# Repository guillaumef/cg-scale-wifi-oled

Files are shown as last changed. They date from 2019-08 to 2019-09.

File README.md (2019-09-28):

# cg-scale-wifi-oled

A fresh, completely refactored design and rewrote code highly inspired by the original and innovative Olkal cg-scale design.

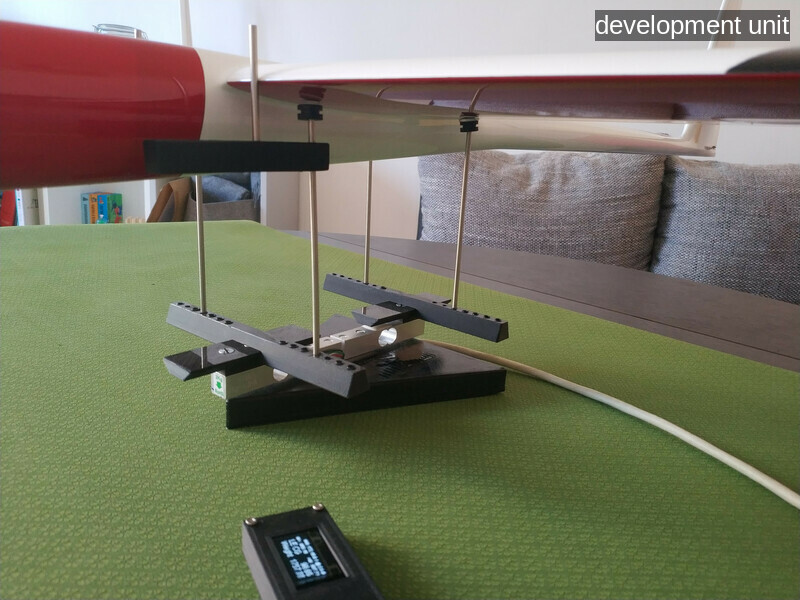
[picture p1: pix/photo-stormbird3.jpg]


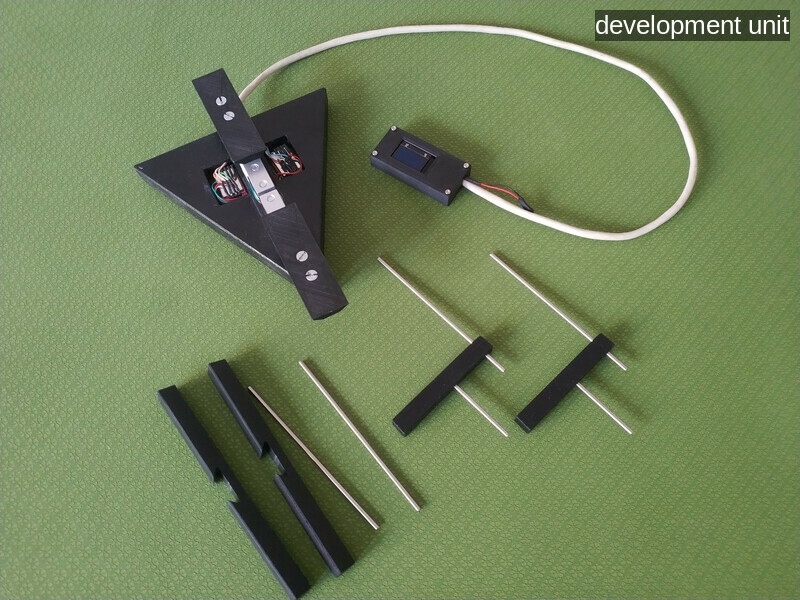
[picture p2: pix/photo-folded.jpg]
CG Scale folded
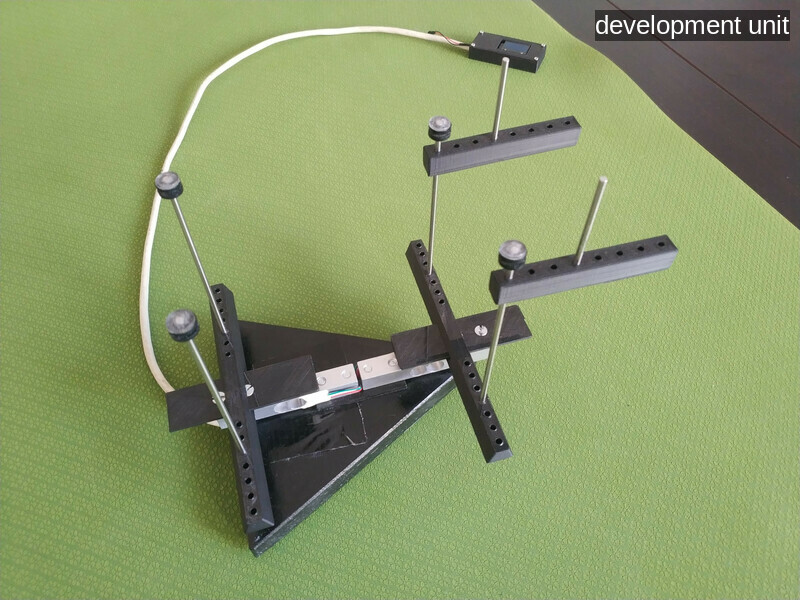
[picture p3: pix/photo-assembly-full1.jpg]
CG Scale ready


## Features

- recent ESP32 wifi-bluetooth-oled board, mainstream and low cost (sub $10) - all-in-one
- minimal and well designed parts (3d printing)
- foldable and easy transport
- manage from a parkflyer, 1m DLG to bigger aerobatic motorised planes (and tunable), and of course F3X gliders
- full remote control: tare, configuration and monitoring via Wifi
- precise tuning
- configuration saved in the ESP32 flash memory
- standalone display with the ESP32 oled
- powered with a simple 1S lipo, a 5V USB battery, Li-Ion 18650, ... 
- multi-language design (included: english, french)
- complete documentation
- easy code upload in the ESP32 with the arduino.cc IDE (few steps documented in 'soft' folder)

The scale 3d parts are parametric and designed with openscad. You can edit the SCAD file and regenerate the STL.

## Comment

Photos were taken from my development unit.
The available parts are now enhanced in strength and stiffness at key points.
Depending on your rc models, you can even trim the rods to lower length to get even more stiffness.
The girder (holding the rods vertically), with its inverted V-shape, is designed to lock itself on the support when a weight is applied.

## Documentation

- [x] Circuit diagram: [CG Scale Circuit Diagram](documentation/circuit-diagram.pdf)
- [x] Assembly: [CG Scale Assembly](documentation/assembly.pdf)
- [x] Manual: [CG Scale Manual](documentation/manual.pdf)
- [x] Soft: [CG Scale Soft](soft/)

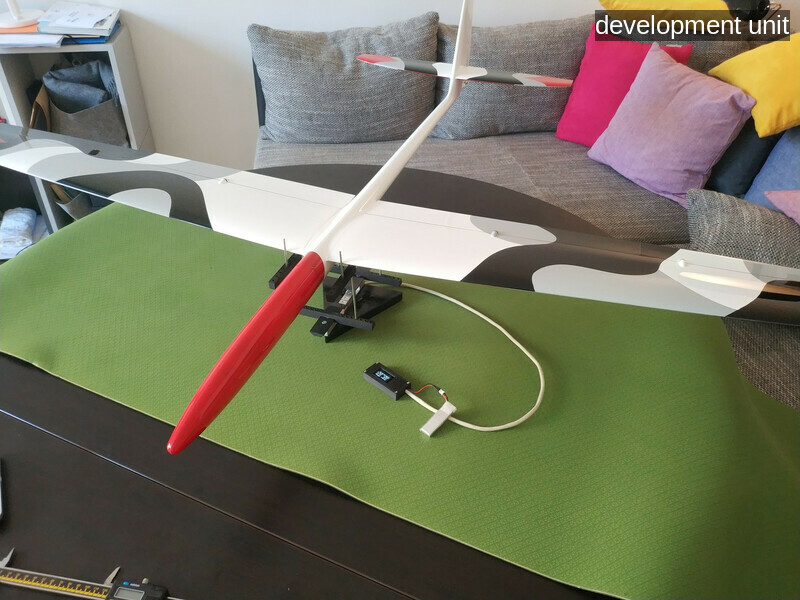
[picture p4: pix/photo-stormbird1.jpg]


## Display/Interface

#### Standalone OLED

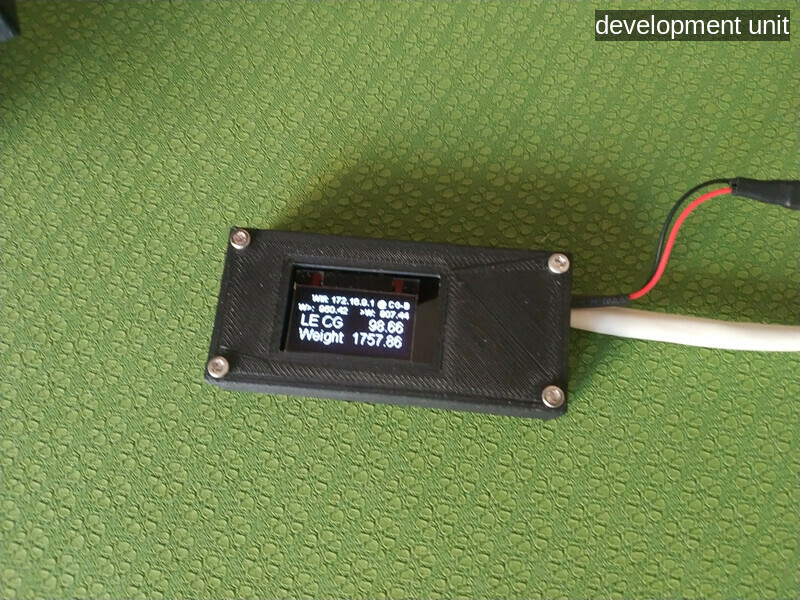
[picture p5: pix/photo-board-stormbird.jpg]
CG Scale board display


#### Wifi interface

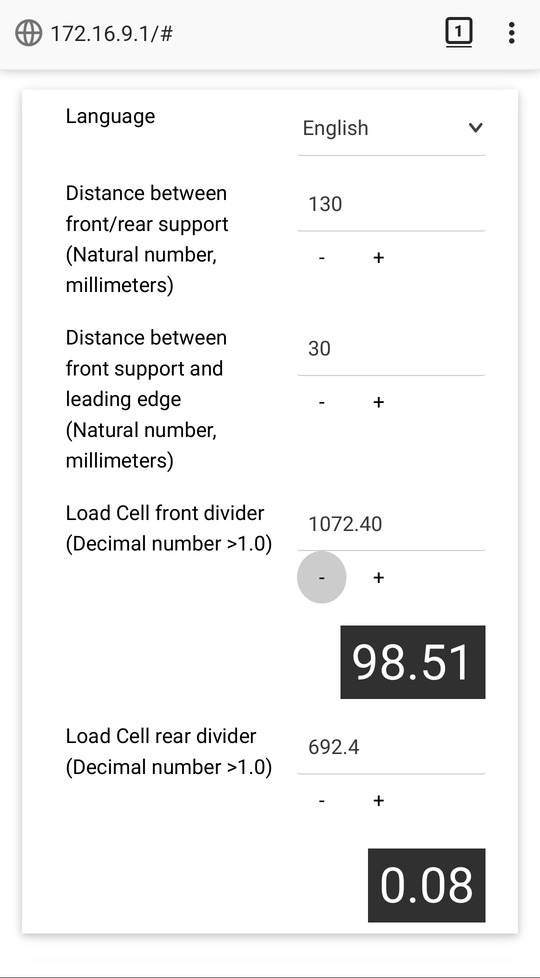
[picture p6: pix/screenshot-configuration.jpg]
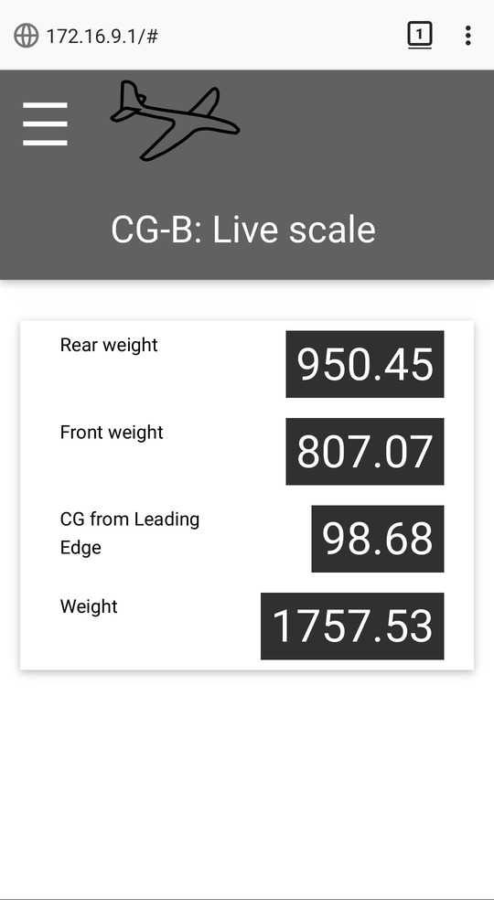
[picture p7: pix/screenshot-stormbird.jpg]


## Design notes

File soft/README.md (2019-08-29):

1) download/install the latest Arduino.cc IDE.

2) in the File > Preferences window in the IDE paste the following line into the Additional Boards Manager URL:

https://dl.espressif.com/dl/package_esp32_index.json

3) go to Tools > Board > Board Manager

4) type ESP32 and Install the new hardware libraries

5) you will be able to find all the ESP32 boards including the Heltec Wifi 32 in the IDE’s board selector:
     "ESP32 Dev Module"

6) go to Tools > Manage Libraries. Search and install those:
     "ESP8266 and ESP32 Oled Driver for SSD1306 display"
     "HX711_ADC"

You are set to compile the 'cgscale.ino' file and flash the board.

Under linux, you can run my Makefile (`make`) to compile and flash to the board.

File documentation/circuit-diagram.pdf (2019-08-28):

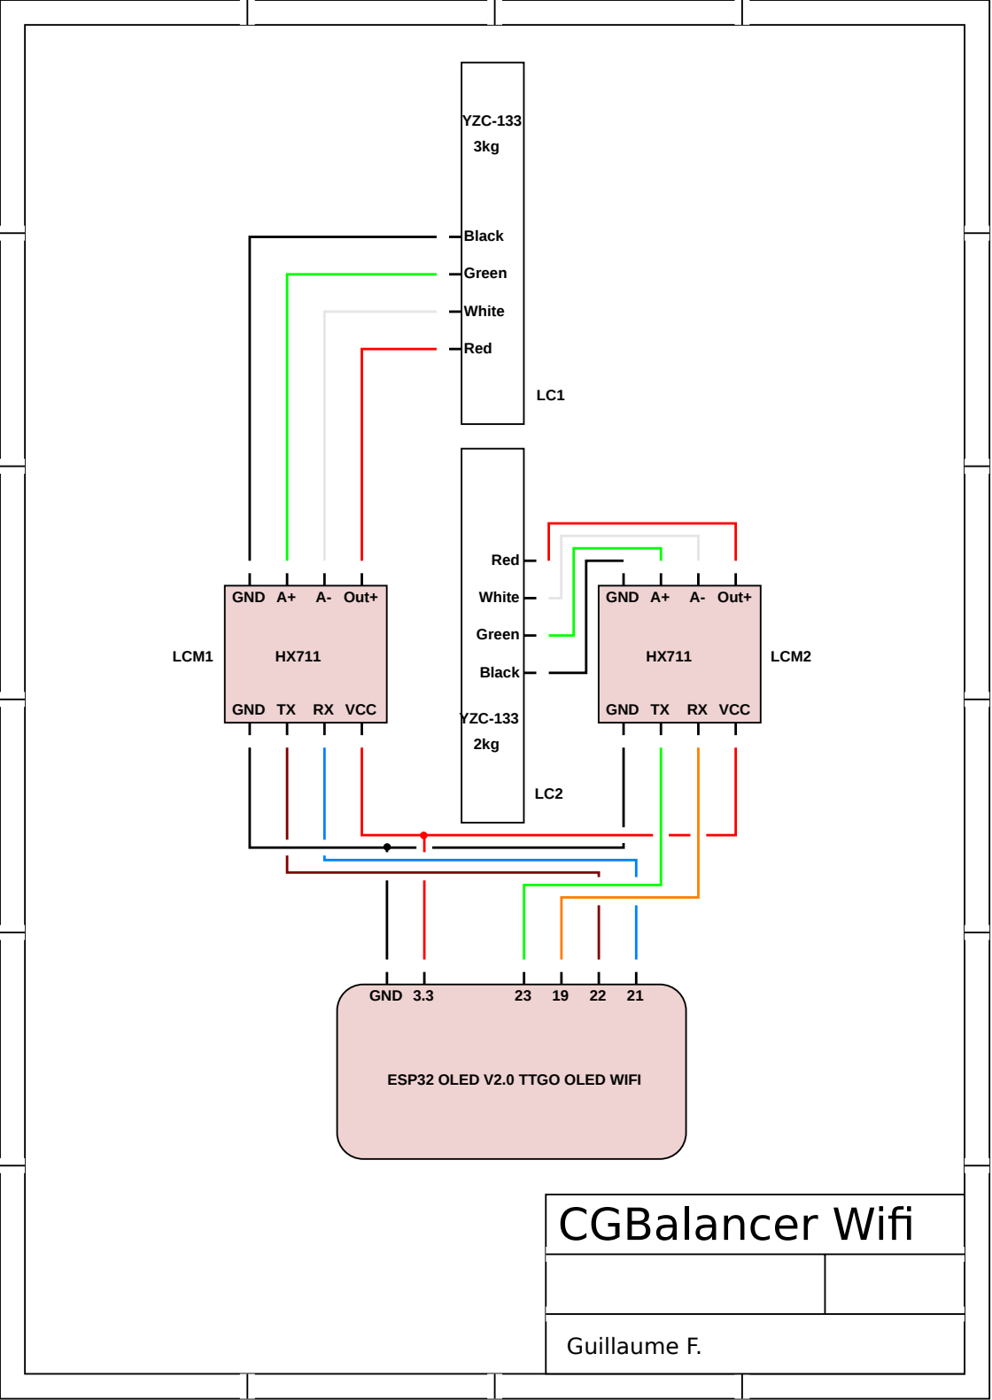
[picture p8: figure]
GND TX RX VCC; GND A+ A- Out+; LCM1; YZC-133; White; Green; Black; Red; LCM2; GND 3.3; ESP32 OLED V2.0 TTGO OLED WIFI; Guillaume F.; CGBalancer Wifi

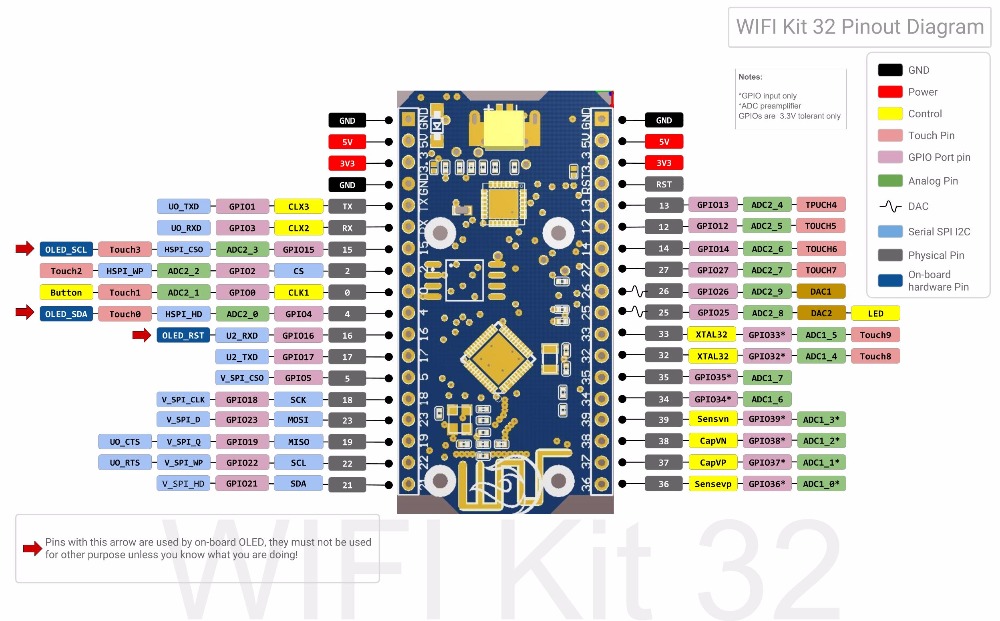
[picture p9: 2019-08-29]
soft/ESP32-TTGO-OLED-DiagramPinout.jpg

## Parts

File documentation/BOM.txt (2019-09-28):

1 x ESP32 OLED V2.0 TTGO (aliexpress)
    "16 Mt bytes (128 Mt bit) Pro ESP32 OLED V2.0 TTGO & for Arduino ESP32 OLED WiFi Modules+Bluetooth Double ESP-32 ESP8266 OLED"
2 x HX711 modules Dual-channel 24-bit A/D (aliexpress - red board - metal shield)
1 x YZC-133 2kg for front scale sensor (aliexpress)
1 x YZC-133 3kg for rear scale sensor (aliexpress)
5 x steel rod 3 mm x ~100-150mm (aliexpress / amazon)
4 x small silicon pad/cap to finish rods end
1 x dead network cable perfect for cabling (scavenging)
4 x screws flat head M4 x 14
4 x screws M5 x 20

Heat Shrink tube
Soldering iron

... and the 3d printed parts.

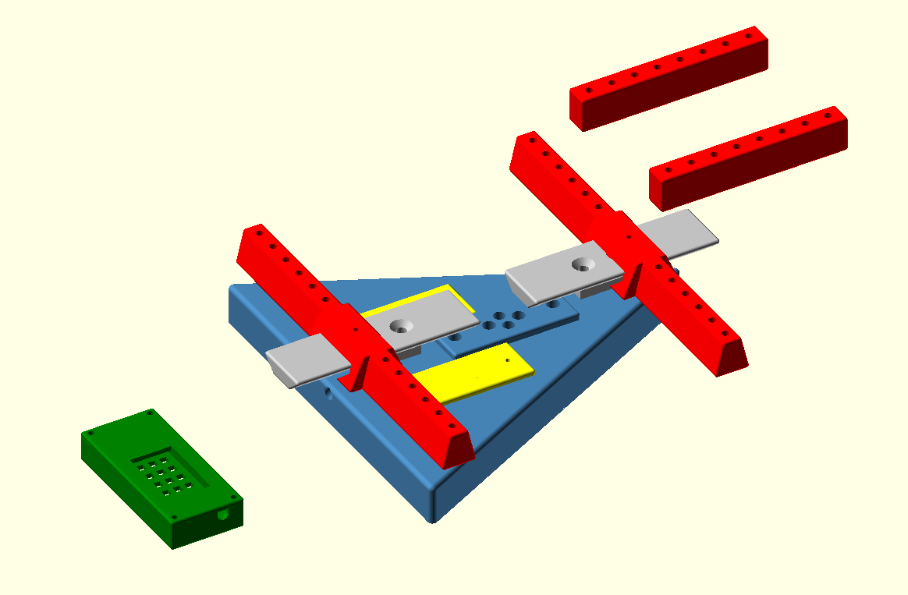
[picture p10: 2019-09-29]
pix/parts-3d-all.png

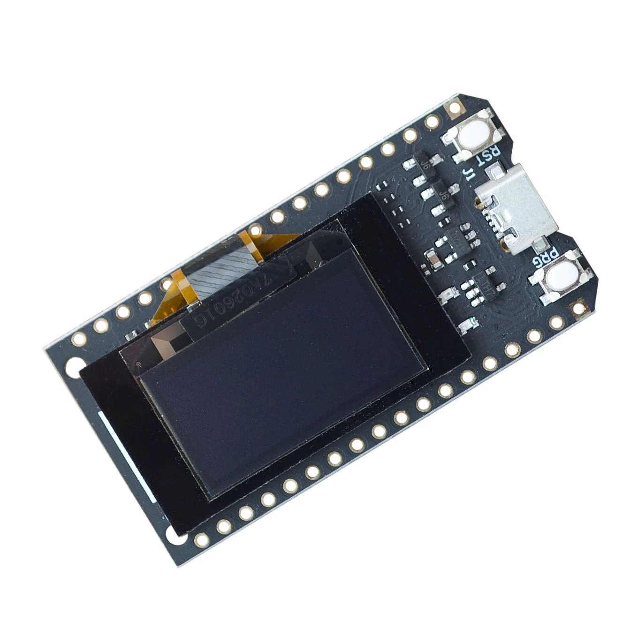
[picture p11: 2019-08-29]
pix/bom-esp32-ttgo-oled-wifi.jpg

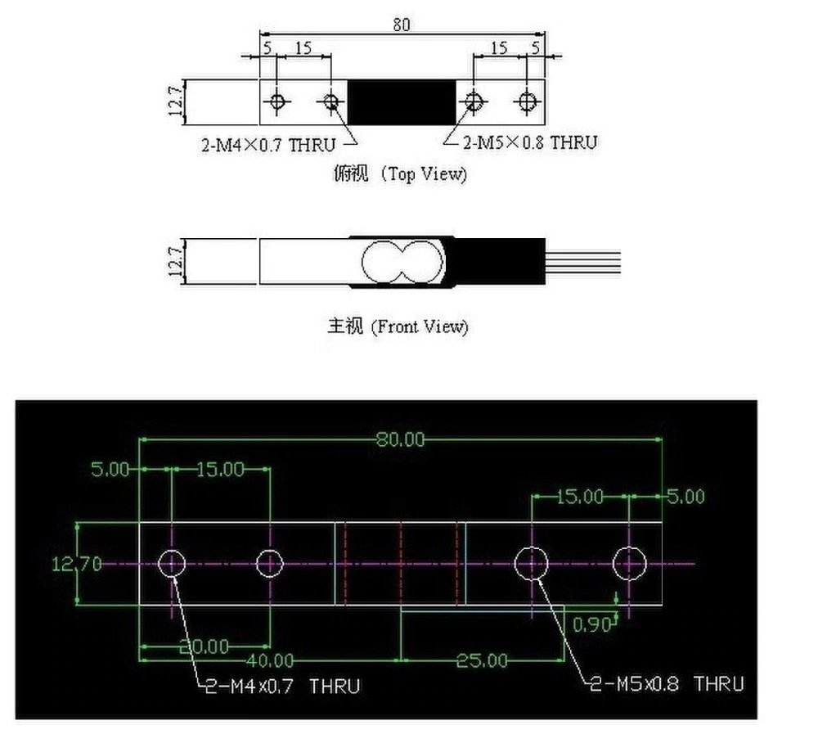
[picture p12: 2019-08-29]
pix/bom-loadcell.jpg

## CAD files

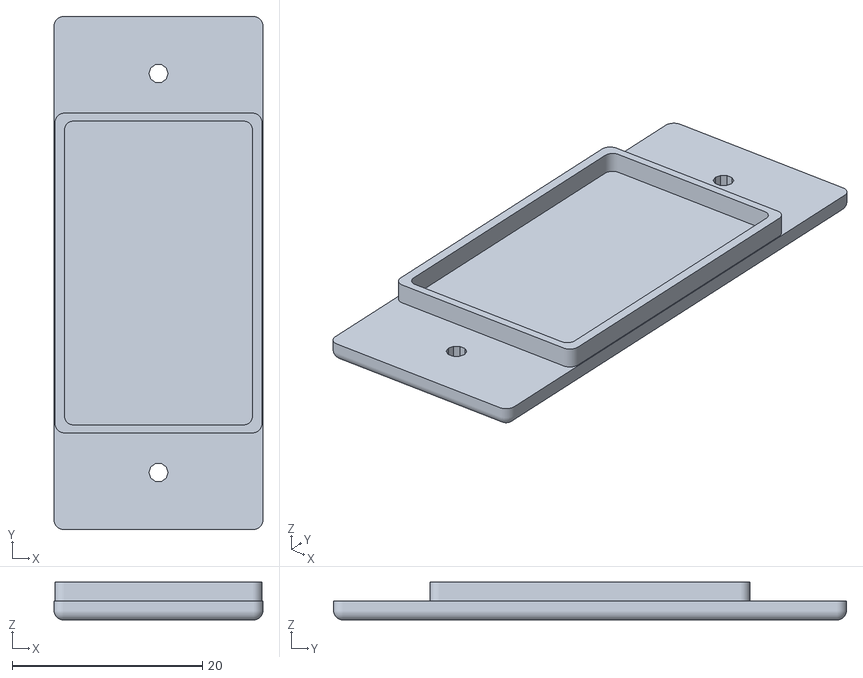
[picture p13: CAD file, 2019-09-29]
parts/stl/base-cover.stl
22.0 x 54.0 x 4.00

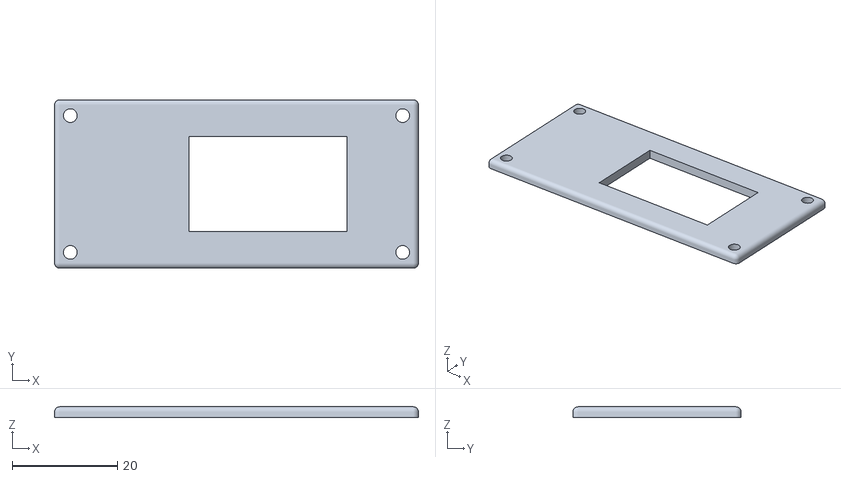
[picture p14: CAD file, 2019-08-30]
parts/stl/case-top.stl
69.2 x 32.0 x 2.00

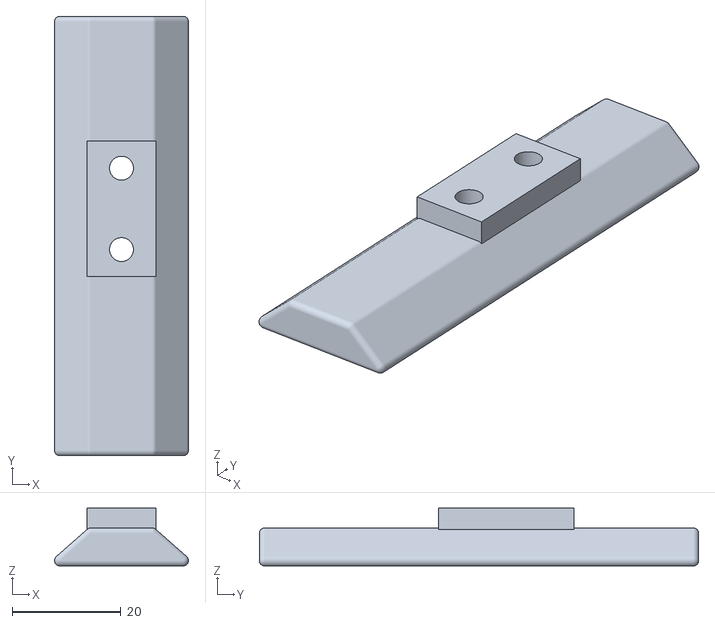
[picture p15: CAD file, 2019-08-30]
parts/stl/support.stl
24.7 x 81.0 x 10.7

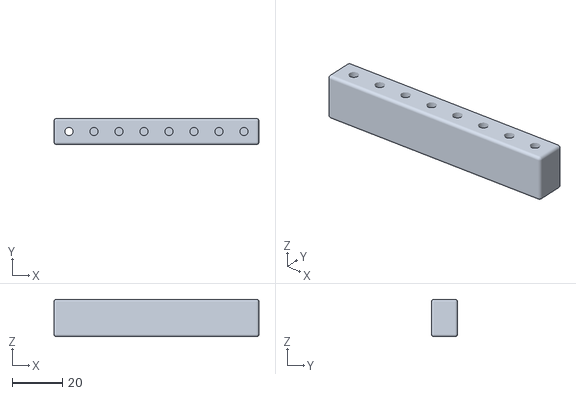
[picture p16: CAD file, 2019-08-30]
parts/stl/le-rod-support.stl
82.0 x 10.5 x 15.0

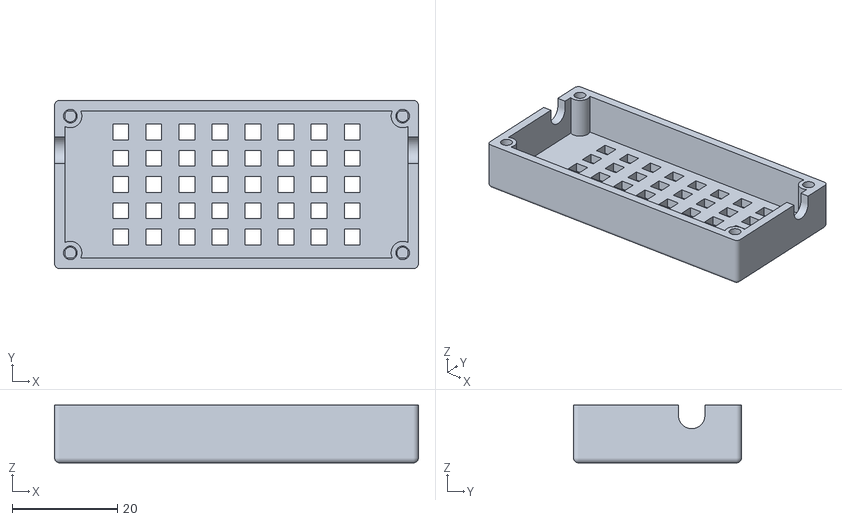
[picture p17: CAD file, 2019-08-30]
parts/stl/case-bottom.stl
69.2 x 32.0 x 11.0

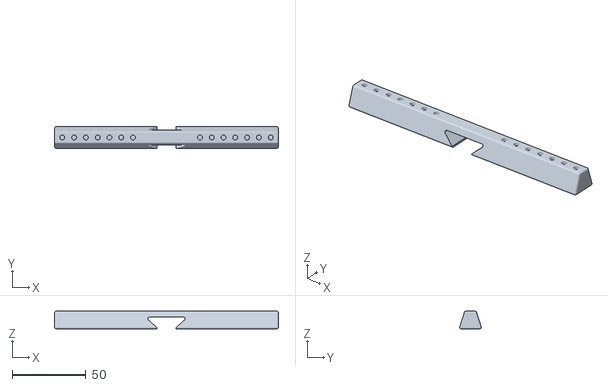
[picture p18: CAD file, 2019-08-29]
parts/stl/rod-support.stl
152.0 x 14.7 x 12.0

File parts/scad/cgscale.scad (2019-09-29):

/*
 * CG Scale
 * Author: Guillaume F. ( g@w0.yt )
 * https://github.com/guillaumef/cg-scale-wifi-oled
 *
 * Work on:
 *    1 - base
 *    2 - support			( x2 )
 *    3 - rod support			( x2 )
 *    4 - leadingEdge rod		( x2 )
 *    5 - case top
 *    6 - case bottom
 *    7 - base scale module cover	( x2 )
 *
 *    9 - display all
 */
WORK_ON = 9;

/* Scale sensor */
ss_wh		= 12.7;	/* x/z */
ss_l		= 80;	/* y */
ss_hole_int_dia	= 5.4;	/* diameter + 0.4 to fit */
ss_hole_ext_dia	= 4.4;	/* diameter + 0.4 to fit */
ss_hole_1 	= 5;
ss_hole_2 	= 20;

/* Scale sensor module */
ssm_w	= 20;
ssm_l	= 32;
ssm_h	= 8;

/* Board */
board_w = 50;
board_l	= 26;
board_h	= 5;
board_oled_w = 30;
board_oled_l = 18;
board_oled_w_pos = 4;
board_clearance = 1;
board_case_thickness = 1; /* with 1 more of the minkowski sphere */
board_case_screw_dia = 2.2;

/* base */
base_w	= 150;	/* width: x */
base_l	= 150;	/* len: depth: y, should be > 2 x ss_l/2 */
base_root_h		= 15;
base_ss_clearance_h	= 4; /* include more with minkowski sphere */
base_ss_clearance_l_space = 3;
base_ss_clearance_l	= (ss_hole_2+ss_hole_1)*2 + base_ss_clearance_l_space;

/* plane support : you can tune */
ps_l_ext	= 39;
ps_l_pos	= 5;
ps_l		= ss_l/2 + ps_l_ext;
ps_lip_h	= 5;

ps_st_l		= 155;
ps_st_h		= 13;
ps_st_hole_depth= 10;
ps_st_hole_dia	= 3.2;	/* 0.2 added to ease the fit - fast drilling in 3mm is mandatory anyway */

$fn=100;


/*
 *
 * SCALE BASE
 *
 */

module base_root() {
	union() {
		difference() {
			minkowski()
			{
				linear_extrude( height = base_root_h )
					polygon( points = [[0, 0],[base_w, 0],[base_w/2,base_l]], convexity = 1 );
				sphere(2);
			}
			/* cut straight the bottom */
			translate([0,0,-base_root_h/2])
					cube([base_w*3,base_l*3,base_root_h], center=true);
		}
		/* ss clearance */
		minkowski()
		{
			translate([base_w/2,base_l/2,base_root_h+base_ss_clearance_h/2])
				cube([ ss_wh+ss_wh/2, base_ss_clearance_l, base_ss_clearance_h ], center=true);
			sphere(1);
		}
	}
}

module base_ss_hole() {
	union() {
		translate([0,0,base_root_h]) {
			cylinder(r=ss_hole_int_dia/2, h=base_root_h*2, center=true);
		}
		cylinder(r=ss_hole_int_dia+2, h=5, center=true);
	}
}
module base_holes() {
	tx = base_w/2;
	ty = base_l/2;
	tz = base_root_h+base_ss_clearance_h/2;
	spacer = base_ss_clearance_l_space/2;
	translate([tx, ty - spacer - ss_hole_1, 0]) base_ss_hole();
	translate([tx, ty - spacer - ss_hole_2, 0]) base_ss_hole();
	translate([tx, ty + spacer + ss_hole_1, 0]) base_ss_hole();
	translate([tx, ty + spacer + ss_hole_2, 0]) base_ss_hole();
}

module base_ssm_hole_mask_hole() {
	translate([0, ssm_l/2 + 5, 0])
		cylinder(r=1,h=1000,center=true,$fn=10);
	translate([0, -(ssm_l/2 + 5), 0])
		cylinder(r=1,h=1000,center=true,$fn=10);
}

module base_ssm_hole_mask_one() {
	minkowski() {
		cube( [ssm_w, ssm_l, ssm_h*2], center=true );
		sphere(1);
	}
}

module ssm_hole_cover() {
	union() {
		difference() {
			translate([0,0,ssm_h+1])
				minkowski() {
					cube( [ ssm_w, ssm_l+20, ssm_h*2], center=true );
					sphere(1);
				}
			translate([0,0,500+2])
				cube([1000,1000,1000],center=true);
			base_ssm_hole_mask_hole();
		}
		difference() {
			translate([0,0,0])
				difference() {
					scale([.99,.99,1])
						translate([0,0,ssm_h+1])
						base_ssm_hole_mask_one();
					scale([.90,.94,1])
						translate([0,0,ssm_h+1])
						base_ssm_hole_mask_one();
				}
			translate([0,0,500+4])
				cube([1000,1000,1000],center=true);
		}
	}
}

module base_ssm_hole_mask() {
	translate([base_w/2 - ssm_w - 2, base_l/2 - ssm_l, base_root_h]) {
		base_ssm_hole_mask_one();
		base_ssm_hole_mask_hole();
	}
	translate([base_w/2 + ssm_w + 2, base_l/2 - ssm_l, base_root_h]) {
		base_ssm_hole_mask_one();
		base_ssm_hole_mask_hole();
	}
}
module base_cablesshole() {
	/* to tune... no complex geometry here - define our vertical hole position */
	ref=37;
	/* ssm hole to under the ss support */
		translate([0,ref/2,2])
		rotate([-90,0,0])
		union() {
			cylinder(r=2.5, h=ref, center=true);
			translate([0,-ref/2+2.5,ref/2])
				rotate([90,0,0])
				cylinder(r=2.5, h=ref, center=true);
		}
}
module base_cablessholes() {
	translate([base_w/2 - ssm_w - 2, base_l/2 - ssm_l, base_root_h-4])
		rotate([0,0,-30])
		base_cablesshole();
	translate([base_w/2 + ssm_w + 2, base_l/2 - ssm_l, base_root_h-4])
		rotate([0,0,30])
		base_cablesshole();
}
module base_cablessmhole() {
	/* to tune... no complex geometry here - define our vertical hole position */
	ref=80;
	/* ssm hole to under the ss support */
		translate([0,0,2.5])
		rotate([-90,0,0])
		union() {
			cylinder(r=2.5, h=ref, center=true);
		}
}
module base_cablessmholes() {
	translate([base_w/2, -2, base_root_h-4])
		rotate([0,0,30])
		base_cablessmhole();
	translate([base_w/2, -2, base_root_h-4])
		rotate([0,0,-30])
		base_cablessmhole();
}
module base() {
	difference() {
		base_root();
		base_holes();
		base_ssm_hole_mask();
		base_cablessholes();
		base_cablessmholes();
	}
}

/*
 *
 * Scale hands
 *
 */
module ps_ss_hole() {
	union() {
		translate([0,0,base_root_h]) {
			cylinder(r=ss_hole_ext_dia/2, h=base_root_h*2, center=true);
		}
		translate([0,0,ss_hole_ext_dia/2])
			cylinder(h=ss_hole_ext_dia+0.1, r1=ss_hole_ext_dia+0.1, r2=0, center=true);
	}
}

module _support_block( w, l, h ) {
	minkowski() {
		translate([-w/2,0,-h/2])
			rotate([90,0,0])
			linear_extrude(height=l,center=true)
			polygon(points = [[0,0],[w/4,h],[w*3/4,h],[w,0]]);
		sphere(1);
	}
}

module _support_block_all() {
	translate([0, -ps_l_pos, ps_lip_h/3]) {
		_support_block( ss_wh+10, ps_l, ps_lip_h );
	}
	translate([ 0, 0, (ss_wh/2 + ps_lip_h)/2 ]) {
		cube([ ss_wh, ss_hole_2+ss_hole_1, ss_wh/2], center=true);
	}
}

module plane_support() {
	difference() {
		translate( [0, (ss_hole_2+ss_hole_1)/2, 0 ] ) {
			_support_block_all();
		}
		translate([0,ss_hole_1,-ps_lip_h/2+0.7])
			ps_ss_hole();
		translate([0,ss_hole_2,-ps_lip_h/2+0.7])
			ps_ss_hole();
	}
}

module rod_support() {
	hole_dia = ps_st_hole_dia;
	difference() {
		rotate([0,0,90]) {
			_support_block( ss_wh, ps_st_l, ps_st_h );
			_support_block( ss_wh*1.8, ss_wh+20, ps_st_h );
		}
		translate([0,0,-2])
		rotate([0,180,0])
			scale([1.03,1.03,1.03])
			_support_block_all();
		cylinder(r=2.1/2,h=100,center=true,$fn=20);
		cylinder(r=4.5/2,h=4,center=true,$fn=6);
		for(x = [ ss_wh+10 : 10 : ps_st_l/2 ]) {
			translate([x,0,ps_st_h - ps_st_hole_depth])
				cylinder(r=hole_dia/2, h=ps_st_h, center=true);
			translate([-x,0,ps_st_h - ps_st_hole_depth])
				cylinder(r=hole_dia/2, h=ps_st_h, center=true);
		}
	}
}

module le_rod_support() {
	hole_dia = ps_st_hole_dia;
	difference() {
		minkowski() {
			cube([ 80, ss_wh*2/3, ps_st_h ], center=true);
			sphere(1);
		}
		/* full hole : thight */
		translate([-35,0,0])
			cylinder(r=hole_dia/2, h=1000, center=true);
		/* rod LE */
		for(x = [ -25 : 10 : 80 ]) {
			translate([x,0, ps_st_h - ps_st_hole_depth])
				cylinder(r=hole_dia/2, h=ps_st_h, center=true);
		}
	}
}

module _case_hole() {
	h = board_h + board_clearance*4 + board_case_thickness*2 + 2; /* +2 for the minkowski sphere */
	translate([0,0,board_case_thickness - 1])
		translate([0,0,h/2 + board_case_thickness*2])
		cylinder(r=board_case_screw_dia/2 + 0.2, h=h + 1, center=true);
}
module _case_screw() {
	h = board_h + board_clearance*4 + board_case_thickness*2 + 2; /* +2 for the minkowski sphere */
	translate([0,0,board_case_thickness - 1])
		difference() {
			cylinder(r=board_case_screw_dia,
					h=h - board_case_thickness, center=true);
			cylinder(r=board_case_screw_dia/2,
					h=h + 1, center=true);
		}
}
module _case() {
	difference() {
		union() {
			difference() {
				minkowski() {
					cube([ board_w + board_clearance*2 + board_case_screw_dia*6 + board_case_thickness*2,
							board_l + board_clearance*2 + board_case_thickness*2,
							board_h + board_clearance*4 + board_case_thickness*2],
							center=true);
					sphere(1);
				}
				cube([ board_w + board_clearance*2 + board_case_screw_dia*6,
						board_l + board_clearance*2,
						board_h + board_clearance*4 ],
						center=true);
				translate([ (board_w - board_oled_w)/2 - board_oled_w_pos, 0, board_h + board_clearance*4 - board_case_thickness*2 ])
					cube([ board_oled_w, board_oled_l, board_case_thickness*6 ], center=true);
			}
			translate([ -board_w/2 - board_case_screw_dia*3, board_l/2, 0 ]) { _case_screw(); }
			translate([ board_w/2 + board_case_screw_dia*3, board_l/2, 0 ]) { _case_screw(); }
			translate([ board_w/2 + board_case_screw_dia*3, -board_l/2, 0 ]) { _case_screw(); }
			translate([ -board_w/2 - board_case_screw_dia*3, -board_l/2, 0 ]) { _case_screw(); }
		}
		translate([ -board_w/2 - board_case_screw_dia*3, board_l/2, 0 ]) { _case_hole(); }
		translate([ board_w/2 + board_case_screw_dia*3, board_l/2, 0 ]) { _case_hole(); }
		translate([ board_w/2 + board_case_screw_dia*3, -board_l/2, 0 ]) { _case_hole(); }
		translate([ -board_w/2 - board_case_screw_dia*3, -board_l/2, 0 ]) { _case_hole(); }
	}
}
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

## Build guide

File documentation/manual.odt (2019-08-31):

# CG Scale configuration

# https://github.com/guillaumef/cg-scale-wifi-oled

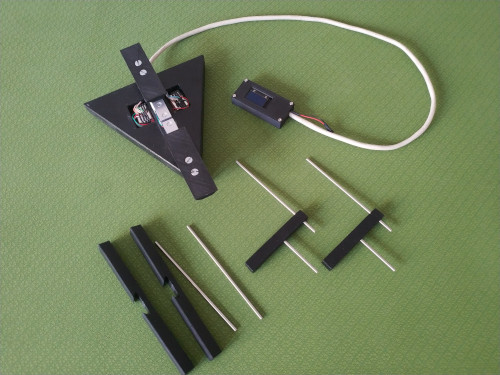
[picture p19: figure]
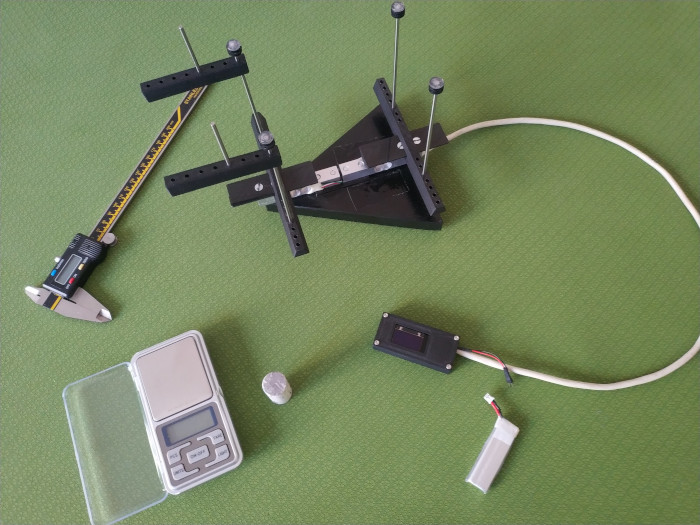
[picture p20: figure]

# First run

Set the scale stable and connect the power of the ESP32.

The first run is displaying:

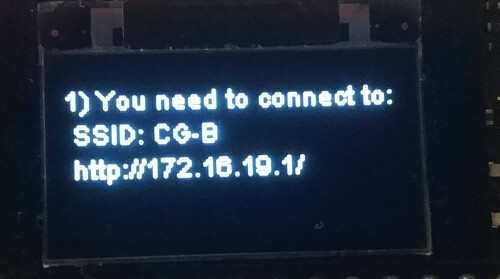
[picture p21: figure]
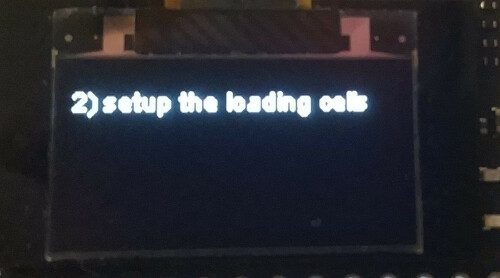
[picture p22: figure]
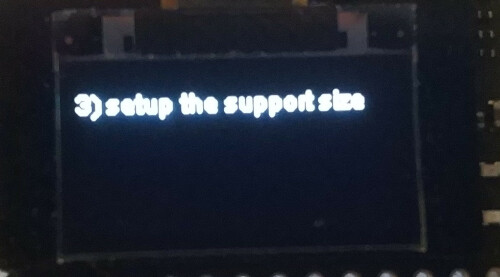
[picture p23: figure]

The ESP32 board opened a Wifi Hotspot named ‘CG-B’.

You can connect your phone/laptop on this SSID (no password).

Your phone/laptop is not going to detect any internet connection, this is normal, stay connected and use your browser to go to the provided address:

http://172.16.19.1/

# Configuration

Left-Top icon holds the menu. Select ‘Configuration’.

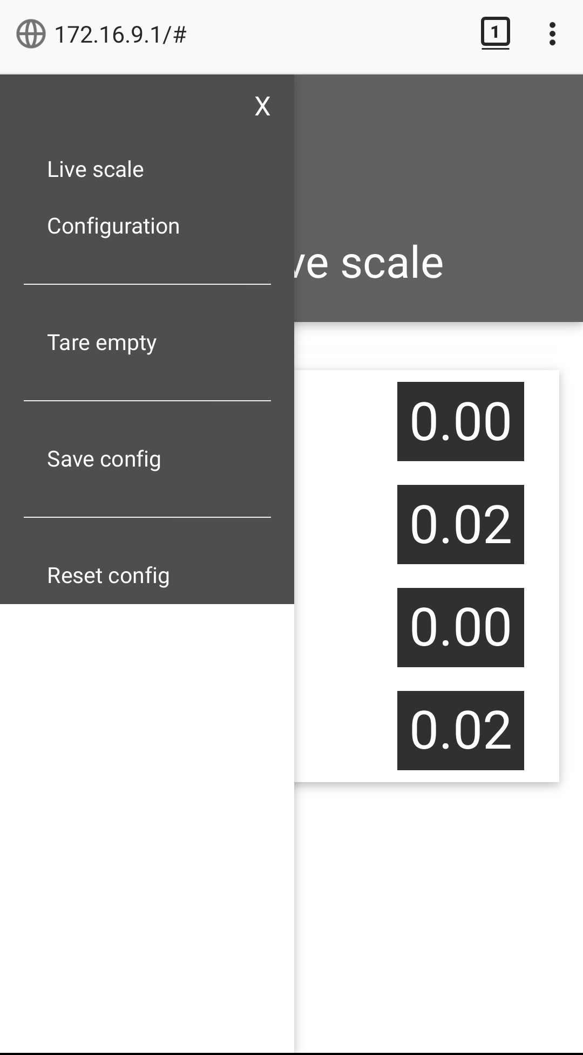
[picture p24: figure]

And this page is displayed:

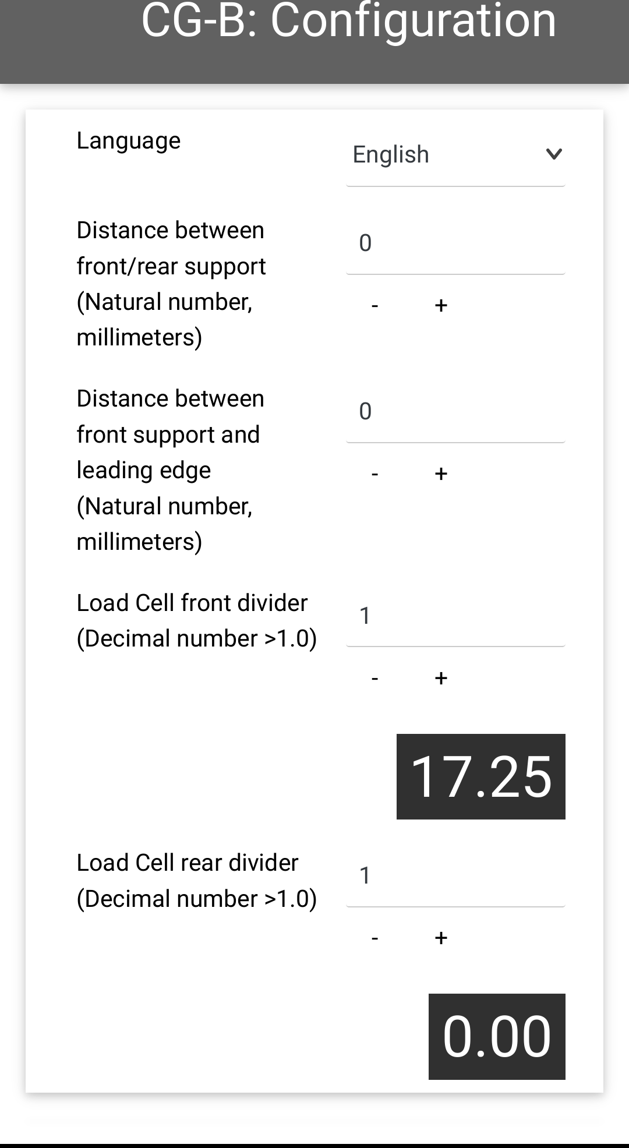
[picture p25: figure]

You have 4 items to configure.

The ~invariable~ ones are the Dividers. We are starting by those.

They are providing to each LoadingCell a common scale to work on. I am using the Gram metric system unit.

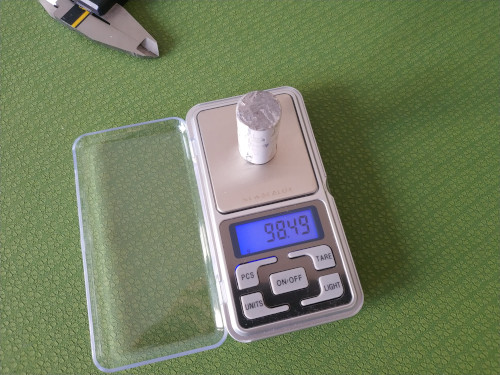
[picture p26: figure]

1. Take a working precision scale and measure a small heavy object (>200gr).

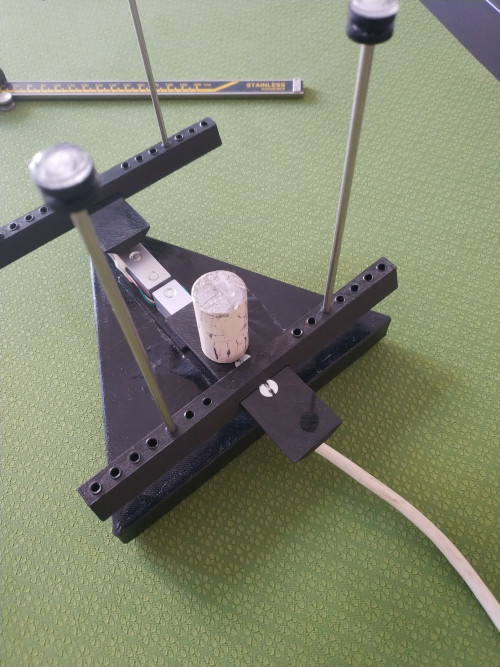
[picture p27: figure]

2. Put this object on a load cell.

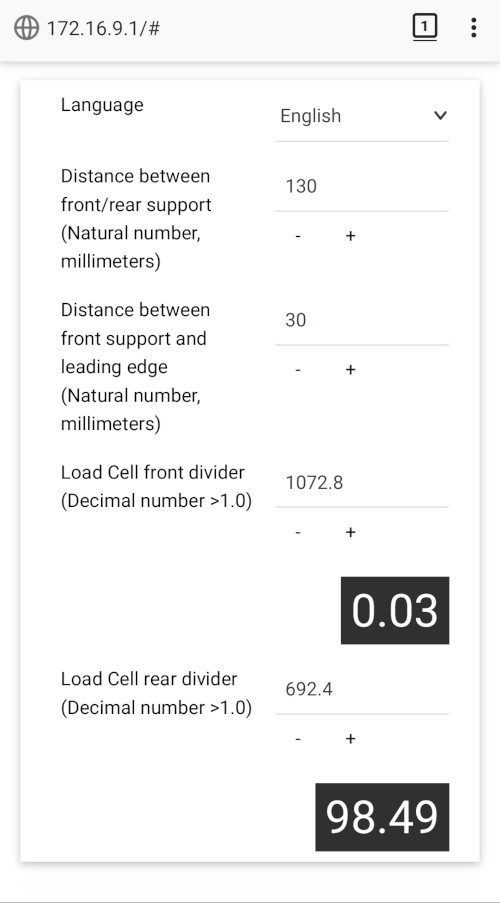
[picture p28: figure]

3. You should see a huge increment in the rear LoadingCell display.
  Change the divider to match the real object weight, typical values are between 500 and 1000.
4. Make the same steps 2-3 for the front LoadingCell

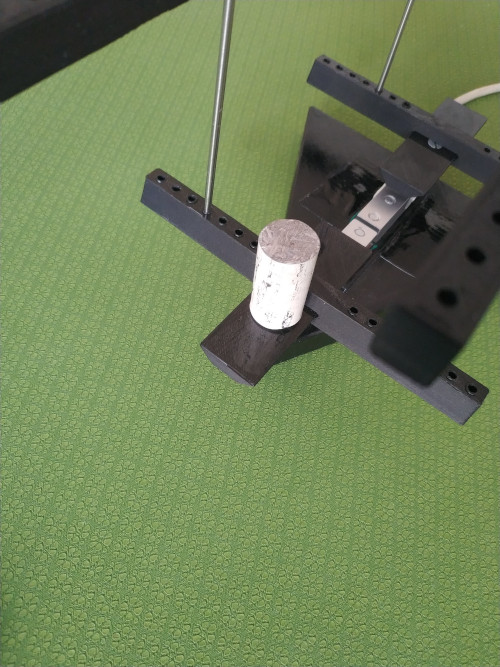
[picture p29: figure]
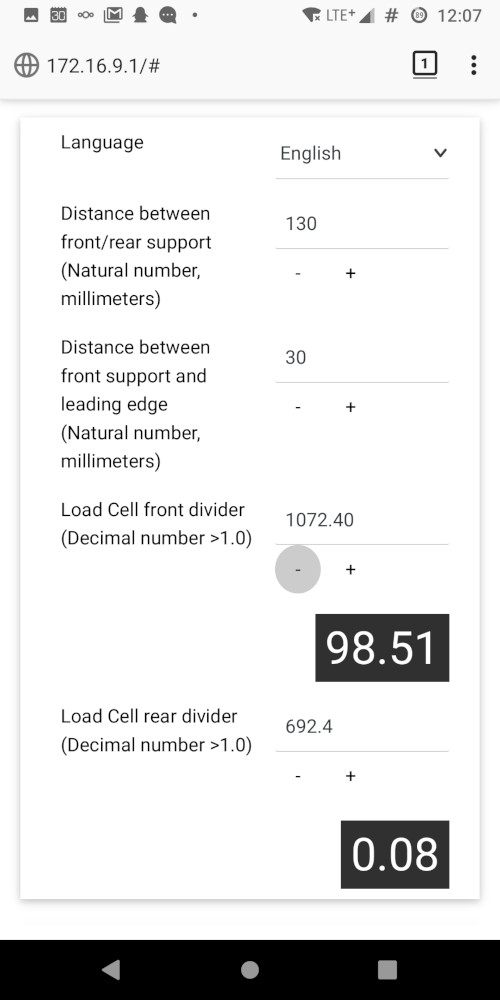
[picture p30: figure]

5. You can save the configuration now (Left-Top menu)
6. This step concerns the more frequent configuration items:

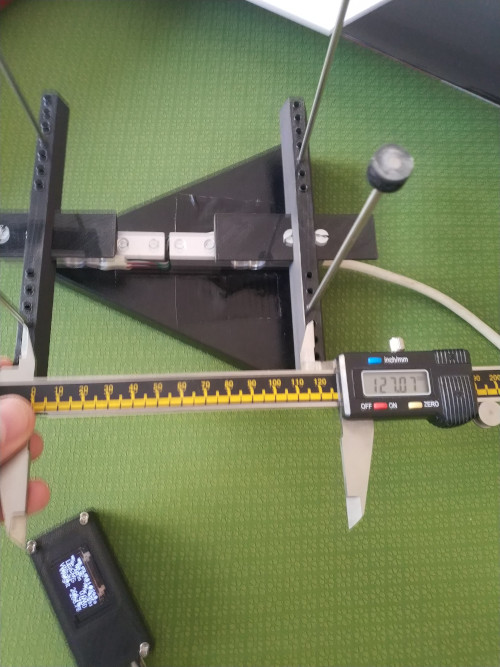
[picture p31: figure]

  1. front rod to rear rod distance:

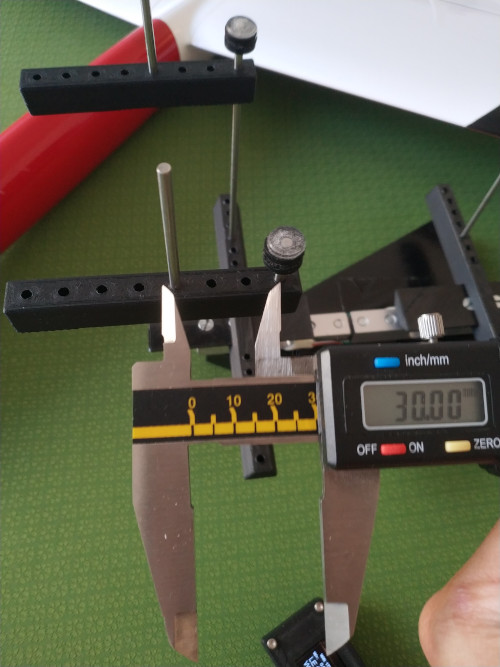
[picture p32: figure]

  1. LeadingEdge rod to front rod distance, this one is easy because each hole is at 10mm from the next one.
  2. Report the values in the configuration and you are ready.

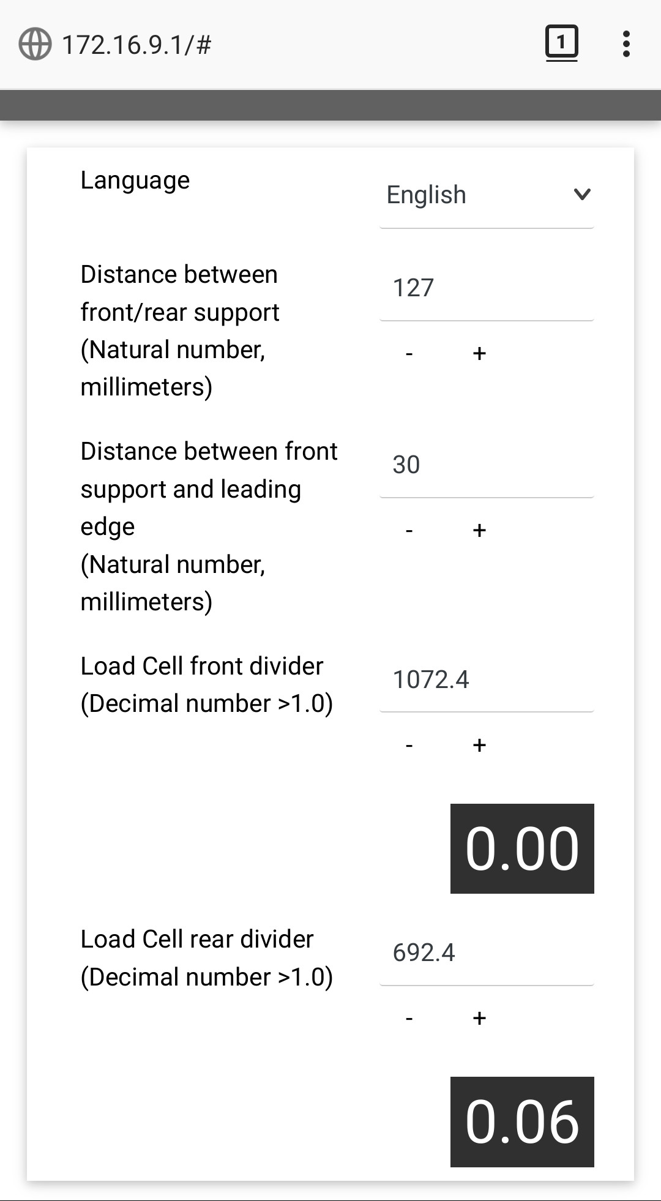
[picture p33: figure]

7. You can save the configuration if you want to keep those two distances or simply set them for the current runtime.

# General: Tare

With the empty scale:

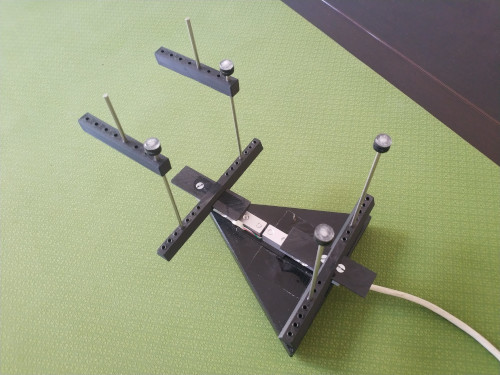
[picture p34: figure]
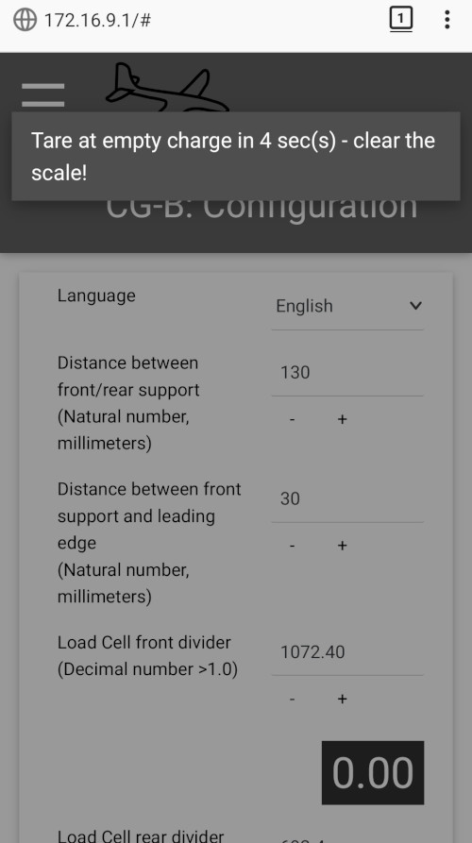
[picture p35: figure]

Click on the Top-Left menu and ‘Tare Empty’.

A countdown is triggered and you have 5 seconds to clear the scale.

The interface tells you when the tare is done (~ 10 seconds for the total procedure).

# Usage

Your CG scale is now fully operationnal, you can put a model on the support rods with the LeadingEdge of the wing against the LE rod.

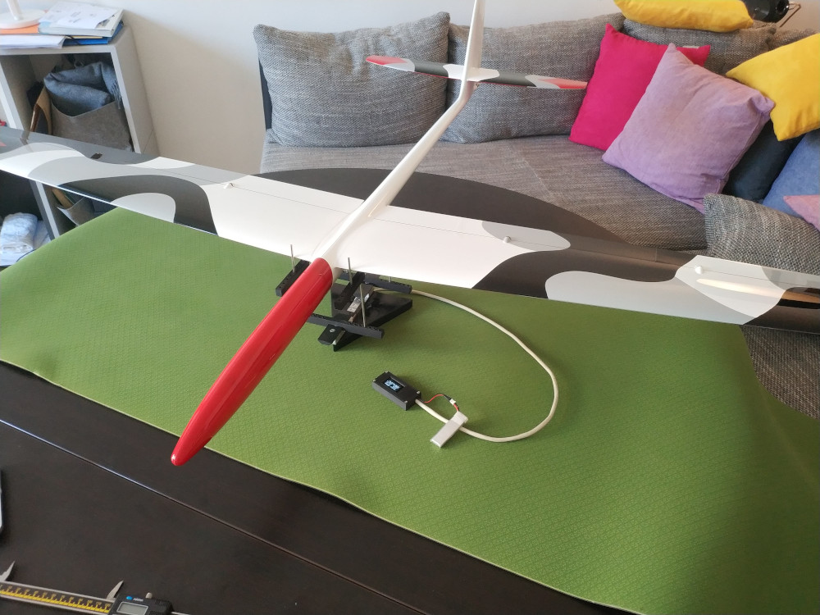
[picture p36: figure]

On the standalone OLED display of the ESP32, you will see a display like this one:

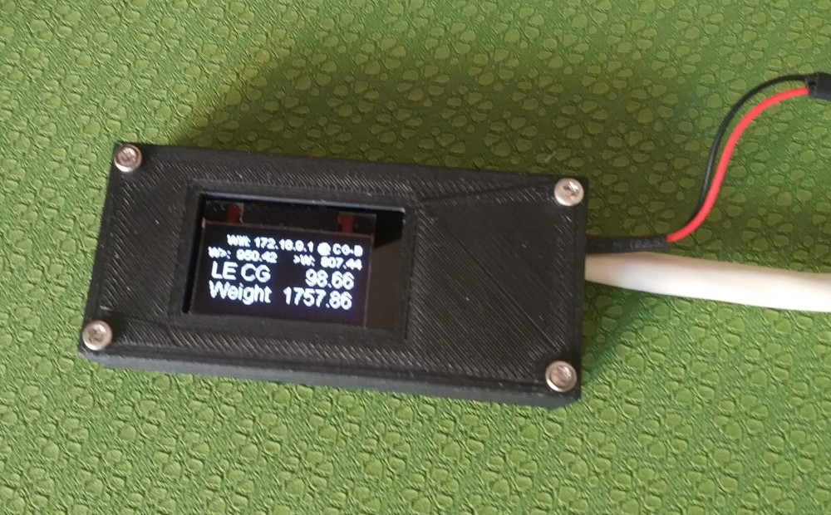
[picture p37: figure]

The ‘live scale’ menu item on your wifi client:

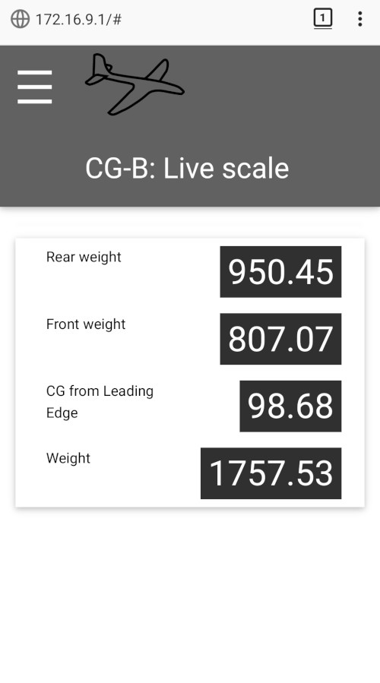
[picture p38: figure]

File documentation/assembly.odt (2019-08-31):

3d parts:

- 1 x base.stl

- 2 x support.stl

- 2 x rod-support.stl

- 2 x le-rod-support.stl

Not mandatory – goodies:

- 1 x case-bottom.stl

- 1 x case-top.stl

1. Take the base.stl part and both LoadingCell
2. Pass the cables of the LoadingCell 3kg throught the hole and screw from the bottom of the base the LoadingCell (floating toward the base large part – the back of the scale)
3. Pass the cables of the LoadingCell 2kg throught the hole and screw from the bottom of the base the LoadingCell (floating toward the base arrow part – the front of the scale)
4. Solder LoadingCell cables to each HX711 module accordingly to the circuit-diagram.pdf (https://github.com/guillaumef/cg-scale-wifi-oled/blob/master/documentation/circuit-diagram.pdf)
5. Prepare a trimmed 8-wires cable (a cat5/6 ethernet cable is a perfect match here) throught the back hole of the base. Partition the 8-wires in two 4-wires and solder them to each HX711 module (circuit-diagram.pdf (https://github.com/guillaumef/cg-scale-wifi-oled/blob/master/documentation/circuit-diagram.pdf))
6. Solder the other end of the 8-wires cable to the ESP32 (circuit-diagram.pdf (https://github.com/guillaumef/cg-scale-wifi-oled/blob/master/documentation/circuit-diagram.pdf))
7. Screw each support.stl parts to each LoadingCell
8. Take a 3mm drill and enhance the quality of all holes on parts: rod-support.stl, le-rod-support.stl
  This step is to perfect the holes to fit the 3mm rods. Don’t over-drill, just follow the printed hole
9. Check a picture of the final cg scale and finalize the build with rods positioning
10. Upload the code in the ESP32 (README.md (https://github.com/guillaumef/cg-scale-wifi-oled/blob/master/soft/README.md))
11. You are now ready and you can read the manual.pdf (https://github.com/guillaumef/cg-scale-wifi-oled/blob/master/documentation/manual.pdf)

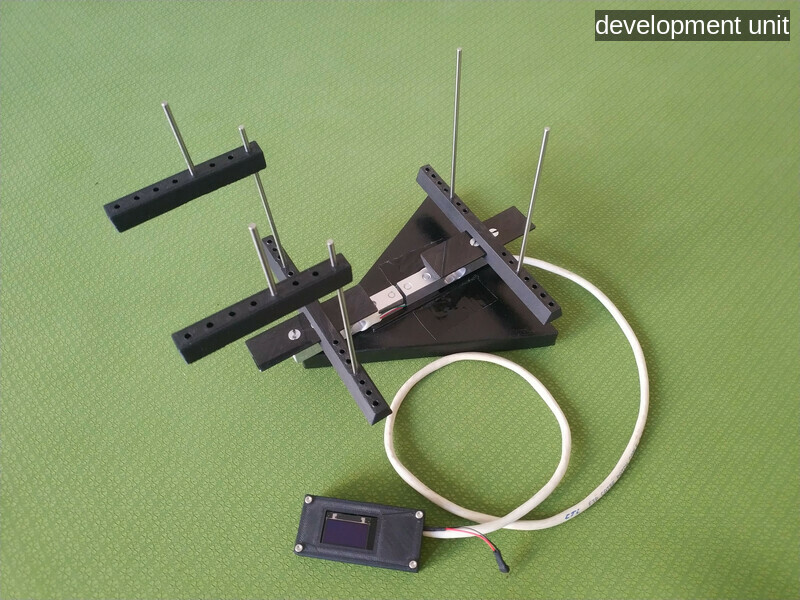
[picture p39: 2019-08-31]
pix/photo-assembly1.jpg

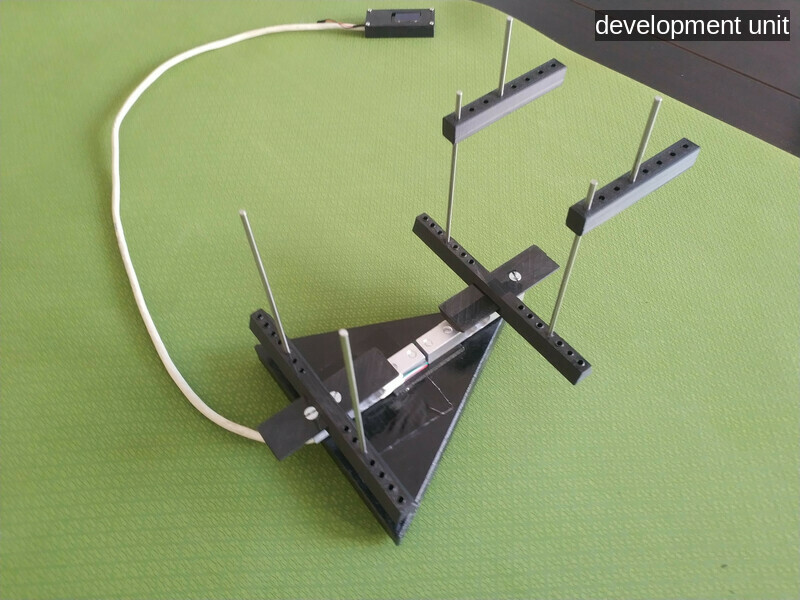
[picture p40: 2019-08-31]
pix/photo-assembly2.jpg

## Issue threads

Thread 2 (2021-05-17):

Reboot after Wifi connection

Prop3r, 2021-05-17:
Bonjour Guillaume,

Thank you for the excellent work and documentation on this CG scale. I'm in the final phase of building the scale, but I'm stuck.

After turning on the device, the splash screen is shown, and after that the instructions to connect to the Wi-Fi appear.
Every time I connect to the Wi-Fi, using my mobile phone, the scale reboots automatically.

I've checked the wiring and boards for continuity and errors, and renewed the scale boards as a precaution, but to no avail.

I've changed the 3,3V connection to the scale boards to 5V. No effect. Main power is provided by a 850mAh 1S lipo (4V).

Do you have any idea what could be wrong?
Is there a log file somewhere I could check?

Cordialement,

Vincent

guillaumef, 2021-05-17:
Bonjour Vincent,

Utilisez-vous la même board que celle que j'ai utilisé?
A mon sens, le problème doit se situer dans le soft et non le hard.
Le Wifi softAP est capricieux, ligne 369-370 - nombreux bugs sont remontés notamment sur les timings.
Essayer d'inserer en ligne 368:
```
    delay(1000);
    WiFi.mode(WIFI_AP);
    delay(1000);
    WiFi.persistent(false);
```

Prop3r, 2021-05-17:
Bonjour Guillaume,

Oui, je Utilisez le ESP32 OLED V2.0 TTGO.

I will try your suggestion, thanks for the quick response!

Cordialement,

Vincent

Prop3r, 2021-05-26:
Bonjour Guillaume,

I was able to successfully connect to the Wifi, without reboots. Thank you!

I could however not connect to the webpage http://172.16.19.1/
After checking the code, I noticed a small error:

IPAddress local_IP(172,16,9,1);
IPAddress gateway(172,16,9,1);

This should be:
IPAddress local_IP(172,16,19,1);
IPAddress gateway(172,16,19,1);

All works now!

Cordialement,

Vincent

guillaumef, 2021-05-28:
Great. I hope you will find it accurate. My two builds are working perfectly (I made a second one with two throw meters and a detachable rj45 cable).

Closed 2021-05-28.

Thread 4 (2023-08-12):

Heltec Wifi kit V2 no longer available, how to make it compatible with V3

Ponpont, 2023-08-12:
Hello,

Many thanks for this project, I had some loadcell available and tried to source a Heltec Wifi Kit V2 but couldn't find any. So I bought a V3 thinking it will be a simple GPIO swap, well long story short, I can't make it work...

Do you think you will be able to port it so it can work on a Heltec Wifi Kit V3 ?

Many thanks,
Pierre

guillaumef, 2023-08-21:
Hi,
It should work with minimal modifications I guess.
Do you successfully compile?

You have to use the provided OLED driver by Heltec it seems and there is a demo here:
https://github.com/HelTecAutomation/Heltec_ESP32/blob/master/examples/OLED/SSD1306UiDemo/SSD1306UiDemo.ino

As far as I can see, there is not much difference in the API, except the includes:
```
#include "heltec.h"
#include "oled/OLEDDisplayUi.h"
```

kabelbrand, 2024-06-29:
Hi,

same here! Found this brilliant scale but the ESP32 is not available. So i got a TTGO  T-Display, tried to implement all libraries, but it doesn't compile. Because i am not a code guy, help will be appreciated....

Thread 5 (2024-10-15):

ESP32

Yanick59, 2024-10-15:
Bonjour,
je souhaite fabriquer votre balance, pouvez vous me conseiller sur l'ESP32 à acquérir ?

Cordialement.

PAT14440, 2024-10-16:
Bonjour,

Si c'est la balance de centrage , c'est celui là

[image: image.png]

Le mar. 15 oct. 2024 à 19:28, Yanick59 ***@***.***> a écrit :

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

Yanick59, 2024-10-16:
Bonjour,

merci de votre réponse mais impossible de voir l'image.......
Si vous avez un lien ça sera plus simple.

Merci

PAT14440, 2024-10-16:
https://fr.aliexpress.com/item/1005006133588398.html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

Le mer. 16 oct. 2024 à 09:35, Yanick59 ***@***.***> a écrit :

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

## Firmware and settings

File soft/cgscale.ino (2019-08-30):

// vim: set ft=c:
/*
 * CG Scale
 * Author: Guillaume F.
 * https://github.com/guillaumef/cg-scale-wifi-oled
 *
 * CG Scale w/ Oled w/ Wifi
 *
 * You can tune the SSID, IP, GPIO, ...
 *
 */

#include <Wire.h>

#include <HX711_ADC.h>

#include <WiFi.h>
#include <WiFiClient.h>
#include <WiFiAP.h>

#include <SSD1306.h>
#include <OLEDDisplayUi.h>

#include <EEPROM.h>


#include "html.h"

/* Uncomment to enable console */
// #define SERIAL_DEBUG

/*
 * Delay loading steps - time to see - set to 0 for fast
 * loading
 */
#define DELAY_STEPS     50

/*
 * Refresh every 1/10th of FPS
 */
#define SCALE_GATHER_FREQ 10

/* LoadCell GPIO */
#define D_LC_FRONT_DOUT	21
#define D_LC_FRONT_SCK	22
#define D_LC_REAR_DOUT	19
#define D_LC_REAR_SCK	  23
#define LC_STABILISING_TIME  4000

/* Wifi SSID */
#define WIFI_SSID       "CG-B"

/* Welcome plane (FPS->seconds) */
#define WELCOME_PLANE   90

/* Do not display negative values */
#define NO_NEGATIVE
/* Max weight tolerate */
#define WEIGHT_MAX      9999.99
/* Min weight on each cell to compute CG */
#define WEIGHT_MIN_CG   30.0

/*
 * Console
 */
#ifdef SERIAL_DEBUG
  void
c_init()
{
  Serial.begin(115200);
  Serial.println();
  Serial.println();
}
  void
c_print( String s )
{
  Serial.println( s );
}
#else
#define c_init()
#define c_print(s)
#endif


/*
 *
 * Conf w/r
 *
 */
#define CONF_MAGIC    ((uint16_t)0xef10)
#define CONF_VERS     ((uint8_t)1)

struct config_s
{
  uint16_t  magic;
  uint8_t   vers;
  uint8_t   lang;
  long		  supports_dist;
  long		  support_le_dist;
  float		  lc_front_calfactor;
  float		  lc_rear_calfactor;
} configuration;

/* EEProm write config at X... if the eeprom is messy */
#define EEPROM_START    0
/* EEProm bytes : EEPROM_START+sizeof(configuration) */
#define EEPROM_SCOPE    (sizeof(configuration) + EEPROM_START)

  int
conf_write( void )
{
  const byte* p = (const byte*)(const void*)&configuration;
  unsigned int i; int addr = 0, modified = 0;
  configuration.magic = CONF_MAGIC;
  configuration.vers  = CONF_VERS;
  for (i = 0; i < sizeof(configuration); i++, addr++, p++) {
    if (*p!=EEPROM.read( EEPROM_START+addr )){
      EEPROM.write( EEPROM_START+addr, *p );
      modified ++;
    }
  }
  EEPROM.commit();
  c_print( "conf_write: wrote "+String(i)+" bytes" );
  return i;
}

  int
conf_reset( void )
{
  memset( &configuration, 0x0, sizeof(configuration) );
  configuration.lc_front_calfactor =
    configuration.lc_rear_calfactor = 1.0;
}

  bool
conf_is_defined( void )
{
  return (configuration.magic == CONF_MAGIC  &&
          configuration.vers == CONF_VERS)
    ? 1 : 0;
}

  bool
conf_is_valid( void )
{
  return (conf_is_defined()                     &&
          configuration.supports_dist>1         &&
          configuration.support_le_dist>1       &&
          configuration.lc_front_calfactor>1.0  &&
          configuration.lc_rear_calfactor>1.0)
    ? 1 : 0;
}

  void
setup_conf( void )
{
  byte* p = (byte*)(void*)&configuration;
  unsigned int i; int addr = 0;

  EEPROM.begin( EEPROM_SCOPE );

  for (i = 0; i < sizeof(configuration); i++, addr++, p++)
    *p = EEPROM.read( EEPROM_START + addr );

  c_print( "conf_readed: " );
  c_print( " version: "+String(configuration.vers) );
  c_print( " supports_dist: "+String(configuration.supports_dist) );
  c_print( " support_le_dist: "+String(configuration.support_le_dist) );
  c_print( " lc_front_calfactor: "+String(configuration.lc_front_calfactor) );
  c_print( " lc_rear_calfactor: "+String(configuration.lc_rear_calfactor) );

  if (! conf_is_defined()) {
    conf_reset();
  }
}

/*
 * Language
 */
#define LANG_NB         2

const char *_msg[] = {
#define MSG_SETUP_WIFI      0
  "Wifi", "Wifi",
#define MSG_SETUP_LC        1
  "LoadCell tare", "Tare cellule charge",
#define MSG_SETUP_CHECK     2
  "Checks", "Verifications",
#define MSG_SETUP_UI        3
  "UserInterface", "Interface utilisateur",
#define MSG_LE_CG_SMALL     4   /* Leading Edge CG */
  "LE CG", "CG BA",
#define MSG_LE_CG           5
  "LeadingEdge CG", "CG Bord Attaque",
#define MSG_WEIGHT          6
  "Weight", "Poids",
#define MSG_WEIGHT_REAR     7
  "W>", "P>",
#define MSG_WEIGHT_FRONT    8
  ">W", ">P",
#define MSG_WIFI            9
  "Wifi", "Wifi",
#define MSG_CONFIG_REQUIRED 10
  "Configuration required", "Configuration necessaire",
#define MSG_CONFIG_STEP1    11
  "1) You need to connect to:"
    "\n SSID: " WIFI_SSID
    "\n http://172.16.19.1/",
  "1) Connectez-vous au:"
    "\n Wifi: " WIFI_SSID
    "\n http://172.16.19.1/",
#define MSG_CONFIG_STEP2    12
  "2) setup the loading cells",
  "2) config les cellules",
#define MSG_CONFIG_STEP3    13
  "3) setup the support size",
  "3) configurer les\ndimensions du support"
};
  const char *
msgc( int i )
{
  return _msg[ i*LANG_NB + configuration.lang ];
}
  String
msg( int i )
{
  return String(msgc(i));
}

/*
 * LoadCell
 */

#define LC_NB		2
HX711_ADC *lc_front = NULL;
HX711_ADC *lc_rear = NULL;
HX711_ADC *a_lc[ LC_NB ] = { NULL, NULL };
/* Lazy lock ... mono thread... happy arduino */
uint8_t lc_available = 0;

struct lc_data_s
{
  float wf, wr, w, cg;
  String swf, swr, sw, scg;
} lc_data;

  void
setup_loadcell_calfactor( void )
{
  if (lc_available) {
    lc_front->setCalFactor( configuration.lc_front_calfactor );
    lc_rear->setCalFactor( configuration.lc_rear_calfactor );
  }
}

  void
setup_loadcell_tare( )
{
  int8_t	i, rdy = 0;

  c_print(msg(MSG_SETUP_LC));

  if (lc_front && lc_available) {
    lc_available = 0;
    for (i=0; i<LC_NB; i++) {
      a_lc[ i ]->powerDown();
      delete(a_lc[i]);
    }

    delay( 1000 );
  }

  a_lc[0] = lc_front = new HX711_ADC( D_LC_FRONT_DOUT, D_LC_FRONT_SCK );
  a_lc[1] = lc_rear  = new HX711_ADC( D_LC_REAR_DOUT, D_LC_REAR_SCK );

  for (i=0; i<LC_NB; i++)
    a_lc[ i ]->begin( 128 );

  /* No startMultiple - incompatible with new objects */
  /* No start - using millis() to countdown the time without referential */
  uint32_t ms = millis() + LC_STABILISING_TIME;
  do {
    for (i=0; i<LC_NB; i++) {
      a_lc[i]->update();
      a_lc[i]->getData();
      yield();
    }
  } while (millis() < ms);

  for (i=0; i<LC_NB; i++)
    a_lc[i]->tare();

  lc_available = 1;

  setup_loadcell_calfactor();

  delay( DELAY_STEPS );
}

  void
loadcell_gather( void )
{
  float wf, wr, w, cg;

  if (! lc_available) {
    lc_data.wf = lc_data.wr = lc_data.w = lc_data.cg = 0.0;
    lc_data.swf = lc_data.swr = lc_data.sw = lc_data.scg = "?";
    return;
  }

  lc_front->update();
  lc_rear->update();

  wf    = lc_front->getData();
  wr    = lc_rear->getData();
#ifdef NO_NEGATIVE
  if (wf<0.0)   wf = 0.0;
  if (wr<0.0)   wr = 0.0;
#endif
#ifdef WEIGHT_MAX
  if (wf>WEIGHT_MAX)  wf = WEIGHT_MAX;
  if (wr>WEIGHT_MAX)  wr = WEIGHT_MAX;
#endif

  w     = wf + wr;

  if (conf_is_valid()
#ifdef WEIGHT_MIN_CG
      && wf > WEIGHT_MIN_CG && wr > WEIGHT_MIN_CG
#endif
      ) {
    double supports_dist, supports_dist_err, compute;
    supports_dist = configuration.supports_dist;
    compute = (supports_dist * wr) / w;
    /* basic check to remove absurd situations:
     * Over the supports_dist ... the plane should fall from the scale */
    if (compute > supports_dist + configuration.support_le_dist)
      cg = -1.0;
    else
      cg = compute + configuration.support_le_dist;
  }
  else
    cg    = 0.0;

  lc_data.wf  = wf;
  lc_data.wr  = wr;
  lc_data.w   = w;
  lc_data.cg  = cg;

  lc_data.swf = float_string( wf, 2, 7 );
  lc_data.swr = float_string( wr, 2, 7 );
  lc_data.sw  = float_string( w,  2, 7 );
  lc_data.scg = float_string( cg, 2, 7 );
}

/*
 * Wifi
 */
WiFiServer server(80);
IPAddress local_IP(172,16,9,1);
IPAddress gateway(172,16,9,1);
IPAddress subnet(255,255,255,0);

  void
setup_wifi( void )
{
  c_print(msg(MSG_SETUP_WIFI));
  /* Wifi */
  WiFi.softAPConfig( local_IP, gateway, subnet );
  WiFi.softAP( WIFI_SSID );
  server.begin();
  delay( DELAY_STEPS );
}


/*
 * UI
 */
SSD1306  display(0x3c, 4, 15);
OLEDDisplayUi ui     ( &display );

/* Loading last checks */
  void
setup_check( void )
{
  c_print( msg(MSG_SETUP_CHECK) );
  if ( conf_is_valid() ) {
    c_print( "valid" );
  }
  delay( DELAY_STEPS );
}

/* UI : Final */
FrameCallback frames[] = {
#ifdef WELCOME_PLANE
  draw_frame_welcome,
#endif
  draw_frame_scale,
  draw_frame_config1,
  draw_frame_config2,
  draw_frame_config3,
};
#ifdef WELCOME_PLANE
FrameCallback   *frames_welcome = frames;
const int       frames_welcome_nb = 1;
FrameCallback   *frames_live = frames_welcome+frames_welcome_nb;
#else
FrameCallback   *frames_live = frames;
#endif
const int       frames_live_nb = 1;
FrameCallback   *frames_conf = frames_live+frames_live_nb;
const int       frames_conf_nb = 3;
OverlayCallback overlays[] = { ms_overlay };

  void
ui_overlay( int overlay )
{
  if (overlay)
    ui.setOverlays( overlays, sizeof(overlays)/sizeof(OverlayCallback) );
  else
    ui.setOverlays( NULL, 0 );
}

  void
ui_to_conf( )
{
  ui_overlay( 0 );
  ui.disableAutoTransition();
  ui.setTargetFPS( 30 );
  ui.setFrameAnimation( SLIDE_LEFT );
  ui.setFrames( frames_conf, frames_conf_nb );
  ui.enableAutoTransition();
}
  void
ui_to_live( void )
{
  ui_overlay( 1 );
  ui.disableAutoTransition();
  ui.setTargetFPS( String(30 / SCALE_GATHER_FREQ).toInt() );
  ui.setFrames( frames_live, frames_live_nb );
  ui.switchToFrame( 0 );
}
#ifdef WELCOME_PLANE
  void
ui_to_welcome( void )
{
  ui.disableAutoTransition();
  ui.setTargetFPS( 30 );
  ui.setFrames( frames_welcome, frames_welcome_nb );
}
#endif

  void
refresh_ui( void )
{
  if (conf_is_valid()) {
    setup_loadcell_calfactor();
    ui_to_live();
  }
  else
    ui_to_conf();
}

  void
setup_ui( void )
{
  c_print( msg(MSG_SETUP_UI) );
  ui.disableAutoTransition();
  delay( DELAY_STEPS );
  ui.init();
#ifdef WELCOME_PLANE
  ui_to_welcome();
#else
  refresh_ui();
#endif
}

/* Loading */
LoadingStage loading[] = {
  { "-",                      setup_conf          },
  { msgc(MSG_SETUP_WIFI),     setup_wifi          },
  { msgc(MSG_SETUP_LC),       setup_loadcell_tare },
  { msgc(MSG_SETUP_CHECK),    setup_check         },
  { msgc(MSG_SETUP_UI),       setup_ui            }
};

  void
setup_ui_loading( void )
{
  c_init();

  pinMode(16,OUTPUT);
  digitalWrite(16, LOW);  // set GPIO16 low to reset OLED
  delay(50);
  digitalWrite(16, HIGH); // while OLED is running, must set GPIO16 in high

  display.flipScreenVertically();

  delay(3000);

  /* OLEDDisplayUi stuff */
  ui.setTimePerFrame(3000);

  ui.disableAllIndicators();

  ui.init();

  ui.runLoadingProcess( loading, sizeof(loading)/sizeof(LoadingStage) );
}

  String
two_digits( int x )
{
  return ((x<10) ? "0":"")+String(x);
}
  String
float_string( float f, int precision, int l )
{
  String s = String( f, precision );
  String b;
  int missing = l - s.length();
  while (missing-- >0) { b.concat(" "); }
  b.concat(s);
  return b;
}

#ifdef WELCOME_PLANE
static uint16_t welcome_cnt = 0;
#include "plane.h"
  void
draw_frame_welcome( OLEDDisplay *display, OLEDDisplayUiState* state,
                    int16_t x, int16_t y)
{
  if (++welcome_cnt == WELCOME_PLANE)
    refresh_ui();
  else
    display->drawXbm(x+5, y, plane_width, plane_height, plane_bits);
  return;
}
#endif

  void
draw_frame_scale( OLEDDisplay *display, OLEDDisplayUiState* state,
                  int16_t x, int16_t y)
{
  loadcell_gather();

  String swf, swr, sw, scg;
  swf   = lc_data.swf;
  swr   = lc_data.swr;
  sw    = lc_data.sw;
  scg   = lc_data.scg;

  display->setFont(ArialMT_Plain_10);
  display->setTextAlignment(TEXT_ALIGN_LEFT);
  display->drawString( 0 + x, 12 + y, msg(MSG_WEIGHT_REAR) + ": "+ swr );
  display->setTextAlignment(TEXT_ALIGN_RIGHT);
  display->drawString( 128, 12 + y, msg(MSG_WEIGHT_FRONT)+ ": "+ swf );

  display->setFont(ArialMT_Plain_16);
  display->setTextAlignment(TEXT_ALIGN_LEFT);
  display->drawString( 5 + x, 24 + y, msg(MSG_LE_CG_SMALL) );
  display->drawString( 5 + x, 41 + y, msg(MSG_WEIGHT) );
  display->setTextAlignment(TEXT_ALIGN_RIGHT);
  display->drawString( 128-5, 24 + y, scg );
  display->drawString( 128-5, 41 + y, sw );

  c_print( msg(MSG_WEIGHT_REAR) +": "+swr+" / "+
           msg(MSG_WEIGHT_FRONT)+": "+swf );
  c_print( " "+msg(MSG_LE_CG)   +": "+scg );
  c_print( " "+msg(MSG_WEIGHT)  +": "+sw  );
}

  void
draw_frame_config( OLEDDisplay *display, OLEDDisplayUiState* state,
                   int16_t x, int16_t y, int16_t msgid )
{
  display->setFont(ArialMT_Plain_10);
  display->setTextAlignment(TEXT_ALIGN_LEFT);
  display->drawString( 0 + x, 5 + y, msg( msgid ) );
}
  void
draw_frame_config1( OLEDDisplay *display, OLEDDisplayUiState* state,
                    int16_t x, int16_t y )
{
  draw_frame_config( display, state, x, y, MSG_CONFIG_STEP1 );
}
  void
draw_frame_config2( OLEDDisplay *display, OLEDDisplayUiState* state,
                    int16_t x, int16_t y )
{
  draw_frame_config( display, state, x, y, MSG_CONFIG_STEP2 );
}
  void
draw_frame_config3( OLEDDisplay *display, OLEDDisplayUiState* state,
                    int16_t x, int16_t y )
{
  draw_frame_config( display, state, x, y, MSG_CONFIG_STEP3 );
}



  void
ms_overlay( OLEDDisplay *display, OLEDDisplayUiState* state )
{
  display->setTextAlignment(TEXT_ALIGN_RIGHT);
  display->setFont(ArialMT_Plain_10);
  display->drawString(
    128, 0,
    msg(MSG_WIFI)+": "+local_IP.toString() + " @ " + String( WIFI_SSID ) );
}

  int
uri_get( String r, String p, char *b )
{
  int pos, end, end2;
  pos = r.indexOf( "&"+p+"=" );
  if (pos<0) {
    pos = r.indexOf( "?"+p+"=" );
    if (pos<0)
      return 0;
  }
  pos   += p.length()+2;
  end   = r.indexOf("&", pos);
  end2  = r.indexOf(" ", pos);
  if (end<0 || (end2>0 && end2<end))
    end = end2;
  r = ((end<0) ?
          r.substring(pos)
          :
          r.substring(pos, end));
  c_print( "CGIP: "+p+" => "+r );
  if (b)
    r.toCharArray( b, 128 );
  return r.length();
}

  void
processWifiClient( )
{
  WiFiClient client = server.available();
  if (! client) { return; }
  String req = "";
  String currentLine = "";                // make a String to hold incoming data from the client
  while (client.connected()) {            // loop while the client's connected
    if (client.available()) {             // if there's bytes to read from the client,
      char c = client.read();             // read a byte, then
      req += c;
      if (c == '\n') {                    // if the byte is a newline character
        // if the current line is blank, you got two newline characters in a row.
        // that's the end of the client HTTP request, so send a response:
        if (currentLine.length() == 0) {
          bool isjson = 0;
          String json;
          char p[128];

          if (uri_get(req, "getconfig", NULL)) {
            isjson = 1;
            c_print( "GET_CONFIG" );
            json = "{\"lang\":"+String(configuration.lang)+
              ",\"supportsdist\":"+String(configuration.supports_dist)+
              ",\"supportledist\":"+String(configuration.support_le_dist)+
              ",\"lcfrontcal\":"+String(configuration.lc_front_calfactor)+
              ",\"lcrearcal\":"+String(configuration.lc_rear_calfactor)+
              "}";
          }
          else if (uri_get(req, "setconfig", NULL)) {
            int mod = 0;
            c_print( "SET_CONFIG" );
            if (uri_get(req, "lang", p)) {
              configuration.lang = (uint8_t)String(p).toInt(); mod=1; }
            if (uri_get(req, "supportsdist", p)) {
              configuration.supports_dist = String(p).toInt(); mod=1; }
            if (uri_get(req, "supportledist", p)) {
              configuration.support_le_dist = String(p).toInt(); mod=1; }
            if (uri_get(req, "lcfrontcal", p)) {
              configuration.lc_front_calfactor = String(p).toFloat(); mod=2; }
            if (uri_get(req, "lcrearcal", p)) {
              configuration.lc_rear_calfactor = String(p).toFloat(); mod=2; }
            if (uri_get(req, "save", NULL)) {
              mod += conf_write();
            }
            if (uri_get(req, "reset", NULL)) {
              mod += conf_reset();
            }
            isjson = 1;
            json = "{\"err\":false,\"updated\":"+String(mod)+"}";
            if (mod) {
              if (mod == 2) {
                setup_loadcell_calfactor();
              }
              refresh_ui();
            }
          }
          else if (uri_get(req, "getlive", NULL)) {
            isjson = 1;
            if (uri_get(req, "config", NULL)) {
              loadcell_gather();
              json = "{\"err\":false,\"cfg_weight_rear\":\""+lc_data.swr+
                "\",\"cfg_weight_front\":\""+lc_data.swf+"\"}";
            }
            else if (conf_is_valid()) {
              loadcell_gather();
              json = "{\"err\":false,\"weight_rear\":\""+lc_data.swr+
                "\",\"weight_front\":\""+lc_data.swf+
                "\",\"weight\":\""+lc_data.sw+
                "\",\"cg\":\""+lc_data.scg+"\"}";
            }
            else {
              json = "{\"err\":true,\"desc\":\"config\"}";
            }
          }
          else if (uri_get(req, "tare", NULL)) {
            isjson = 1;
            setup_loadcell_tare();
            json = "{\"err\":false}";
          }

          client.println("HTTP/1.1 200 OK");
          client.println("Connection: Keep-Alive");
          client.println("Content-Length: "+
                         String(((isjson)?json.length():strlen(HTML))));
          client.println("Content-type: "+
                         ((isjson)?String("application/json")
                          :String("text/html")));
          client.println();
          if (isjson) {
            client.print( json );
          }
          else {
            client.print( HTML );
          }
          break;

        } else {
          currentLine = "";
        }
      } else if (c != '\r') {
        currentLine += c;
      }
    }
  }
  // close the connection:
  client.stop();
}


/*
 * Main setup
 */
  void
setup()
{
  delay(DELAY_STEPS);
  setup_ui_loading();
}

/*
 * Main loop
 */
  void
loop()
{
  int remainingTimeBudget = ui.update();
  if (remainingTimeBudget > 0) {
    // Wifi new client
    processWifiClient();
  }
}

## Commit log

2019-09-28 BOM update
2019-09-29 scale module cover and locking screw for the rod support
    [base-cover.stl, cgscale.scad]
